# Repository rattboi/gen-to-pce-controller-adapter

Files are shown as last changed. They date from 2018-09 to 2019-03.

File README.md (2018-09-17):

Simple Genesis 3-button to PC-Engine adapter
============================================

Tested on breadboard, test PCBs incoming

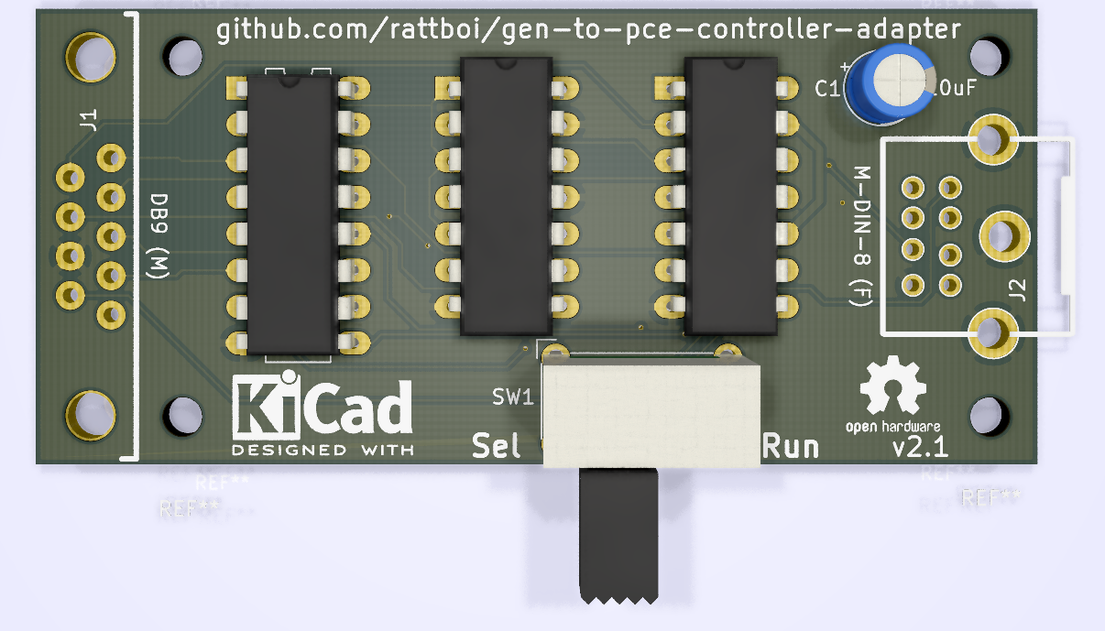
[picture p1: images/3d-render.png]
PCB Front


[pcb_front]: https://github.com/rattboi/gen-to-pce-controller-adapter/raw/master/images/3d-render.png "Front PCB"

Genesis Controller
==================

|Pin | Type | Name (Select=GND) | Name (Select=+5V) |
|----|---|---|---|
|1 | Out  | Up | Up |
|2 | Out  | Down | Down |
|3 | Out  | Gnd | Left |
|4 | Out  | Gnd | Right |
|5 | | +5VDC | +5VDC |
|6 | Out  | Button A | Button B |
|7 | In | Select | Select |
|8 | | Ground | Ground |
|9 | Out  | Start | Button C |

PC-Engine Controller
====================

|Pin | Type | Name (Select=GND) | Name (Select=+5V) |
|----|---|---|---|
|1 | | +5VDC | +5VDC |
|2 | Out  | Button C (I) | Up |
|3 | Out  | Button B (II) | Right |
|4 | Out  | Button A (Sel) | Down |
|5 | Out  | Start | Left |
|6 | In | Select | Select |
|7 | In | /Enable | /Enable |
|8 | | Ground | Ground |

PC-Engine Extension Wiring
==========================

|Pin | Color |
|----|---|
|1 | Brown |
|2 | Red |
|3 | Orange|
|4 | Yellow|
|5 | Green |
|6 | Blue  |
|7 | Purple|
|8 | Black |

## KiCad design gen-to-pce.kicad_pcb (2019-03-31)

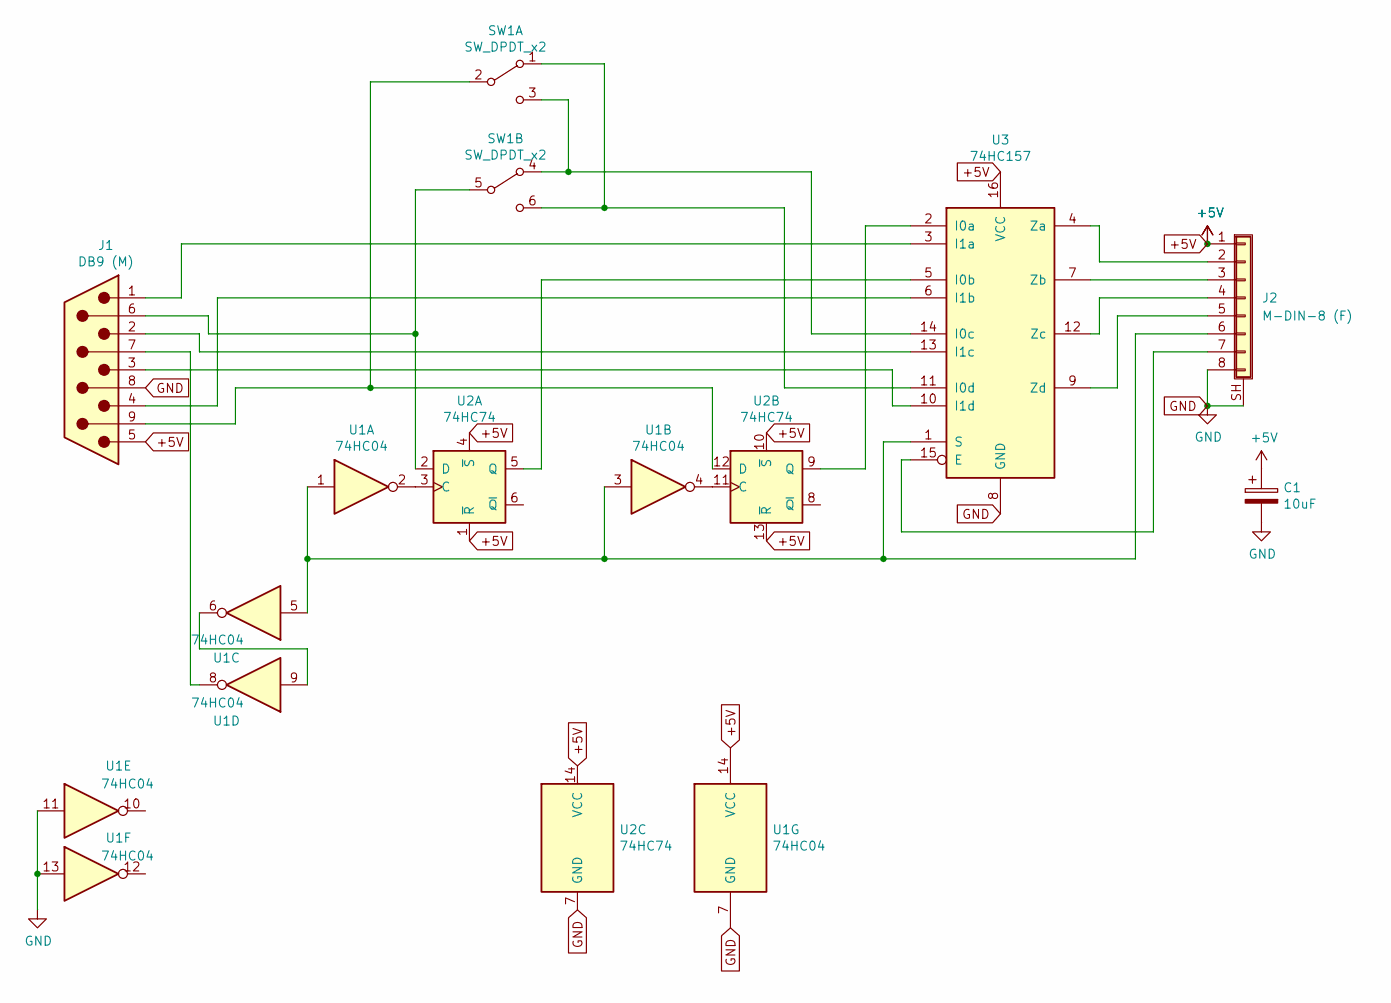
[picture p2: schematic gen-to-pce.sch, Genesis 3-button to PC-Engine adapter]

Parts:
C1: 10uF; CP_Radial_D5.0mm_P2.50mm
J1: DB9 (M); DSUB-9_Jack_5747840-3
J2: M-DIN-8 (F); minidin-8
SW1: SW_DPDT_x2; SW_E-Switch_EG2219_DPDT_Angled
U1: 74HC04; DIP-14_W7.62mm_LongPads
U2: 74HC74; DIP-14_W7.62mm_LongPads
U3: 74HC157; DIP-16_W7.62mm_LongPads

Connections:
+5V: C1.1, J1.5, J2.1, U1.14 (VCC), U2.1 (~R), U2.4 (~S), U2.10 (~S), U2.13 (~R), U2.14 (VCC), U3.16 (VCC)
GND: C1.2, J1.8, J2.8, J2.SH (Shield), U1.7 (GND), U1.11, U1.13, U2.7 (GND), U3.8 (GND)
unnamed: J1.1, U3.3 (I1a)
unnamed: J1.2, U3.13 (I1c)
unnamed: J1.3, U3.10 (I1d)
unnamed: J1.4, U3.6 (I1b)
unnamed: J1.6, SW1.5 (B), U2.2 (D)
unnamed: J1.7, U1.8
unnamed: J1.9, SW1.2 (B), U2.12 (D)
unnamed: J2.2, U3.4 (Za)
unnamed: J2.3, U3.7 (Zb)
unnamed: J2.4, U3.12 (Zc)
unnamed: J2.5, U3.9 (Zd)
unnamed: J2.6, U1.1, U1.3, U1.5, U3.1 (S)
unnamed: J2.7, U3.15 (E)
unnamed: SW1.1 (A), SW1.6 (C), U3.11 (I0d)
unnamed: SW1.3 (C), SW1.4 (A), U3.14 (I0c)
unnamed: U1.2, U2.3 (C)
unnamed: U1.4, U2.11 (C)
unnamed: U1.6, U1.9
unnamed: U2.5 (Q), U3.5 (I0b)
unnamed: U2.9 (Q), U3.2 (I0a)

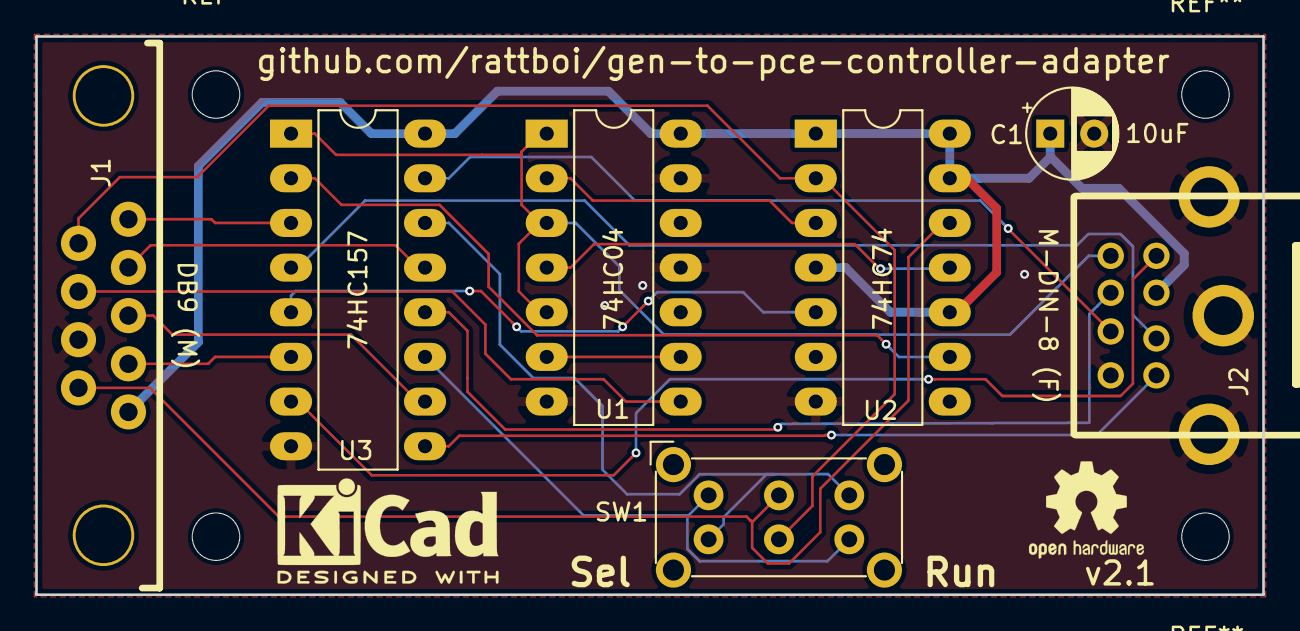
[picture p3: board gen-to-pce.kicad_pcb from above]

Board: 2 copper layers, 69.8 x 31.8 mm, 7 parts (0 on the bottom side), 22 nets.

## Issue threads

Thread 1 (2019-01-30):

Down and Left incorrectly swapped?

CZroe, 2019-01-30:
It appears that the schematic has J1 pin 2 (MD Down) to U3 pin 13 (PCE Left) and J1 pin 3 (MD Left) to U3 pin 10 (PCE Down).

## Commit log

2018-09-06 Added extension cable color guide
2018-09-06 Fixed button swap B/C. Apparently PCE is II, then I
    [gen-to-pce.sch]
2018-09-08 First pass at PCB. Needs some work. I don't know what I'm doing, lol
    [gen-to-pce.kicad_pcb, gen-to-pce.sch]
2018-09-08 More silkscreen labels, better traces
    [gen-to-pce.kicad_pcb]
2018-09-10 Ground fill, larger power traces, rectanglular edge cuts
    [gen-to-pce.kicad_pcb, gen-to-pce.sch]
2018-09-10 M-din-8 mount holes plated, select line delay
    Added select line delay for genesis controller to make sure there's no
    problem with propagation delay and setup time.
    [gen-to-pce.kicad_pcb, gen-to-pce.sch]
2018-09-11 Fixed up silkscreen, added oshw + kicad logos
    [gen-to-pce.kicad_pcb]
2018-09-17 Archive modules, move J2 silkscreen onto pcb
    [gen-to-pce.kicad_pcb]
2018-09-17 Add DPDT switch, reroute to account for switch
    The switch swaps the A button and Start button, which makes it the same
    as an Avenue Pad 3, basically. With the Avenue Pad 3, the extra button
    exists where the A button is on the Genesis, and the mapping is selected
    by a switch on the controller. Some games use III mapped to Sel, some
    use III mapped to Run.
    The original design had A (which you can consider III) hard-mapped to
    Sel. Now it is selectable, which increases compatibility with games that
    mapped III to Run instead.
    [gen-to-pce.kicad_pcb, gen-to-pce.sch]
2018-09-17 Added 3d render from kicad, removed Oshpark renders
    This one has the switch
2018-09-17 Add III button (A on genesis) mapping to silkscreen
    [gen-to-pce.kicad_pcb]
2018-09-24 Flip text around to match text on chips
    [gen-to-pce.kicad_pcb]
2019-03-31 Update to v2.1, wider +5V traces, added decoupling cap
    [gen-to-pce.kicad_pcb, gen-to-pce.sch]
